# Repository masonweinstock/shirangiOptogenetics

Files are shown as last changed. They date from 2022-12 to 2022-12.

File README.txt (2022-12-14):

12/14/2022

Unless otherwise noted, all scripts, designs, and circuits were designed and created by Mason Weinstock.

Contained here are notes of the hardware and software used to execute optogenetic experiments in Dr. Shirangi's research at Villanova University from 2021 onward.

Questions should be directed to research@qyka.org.

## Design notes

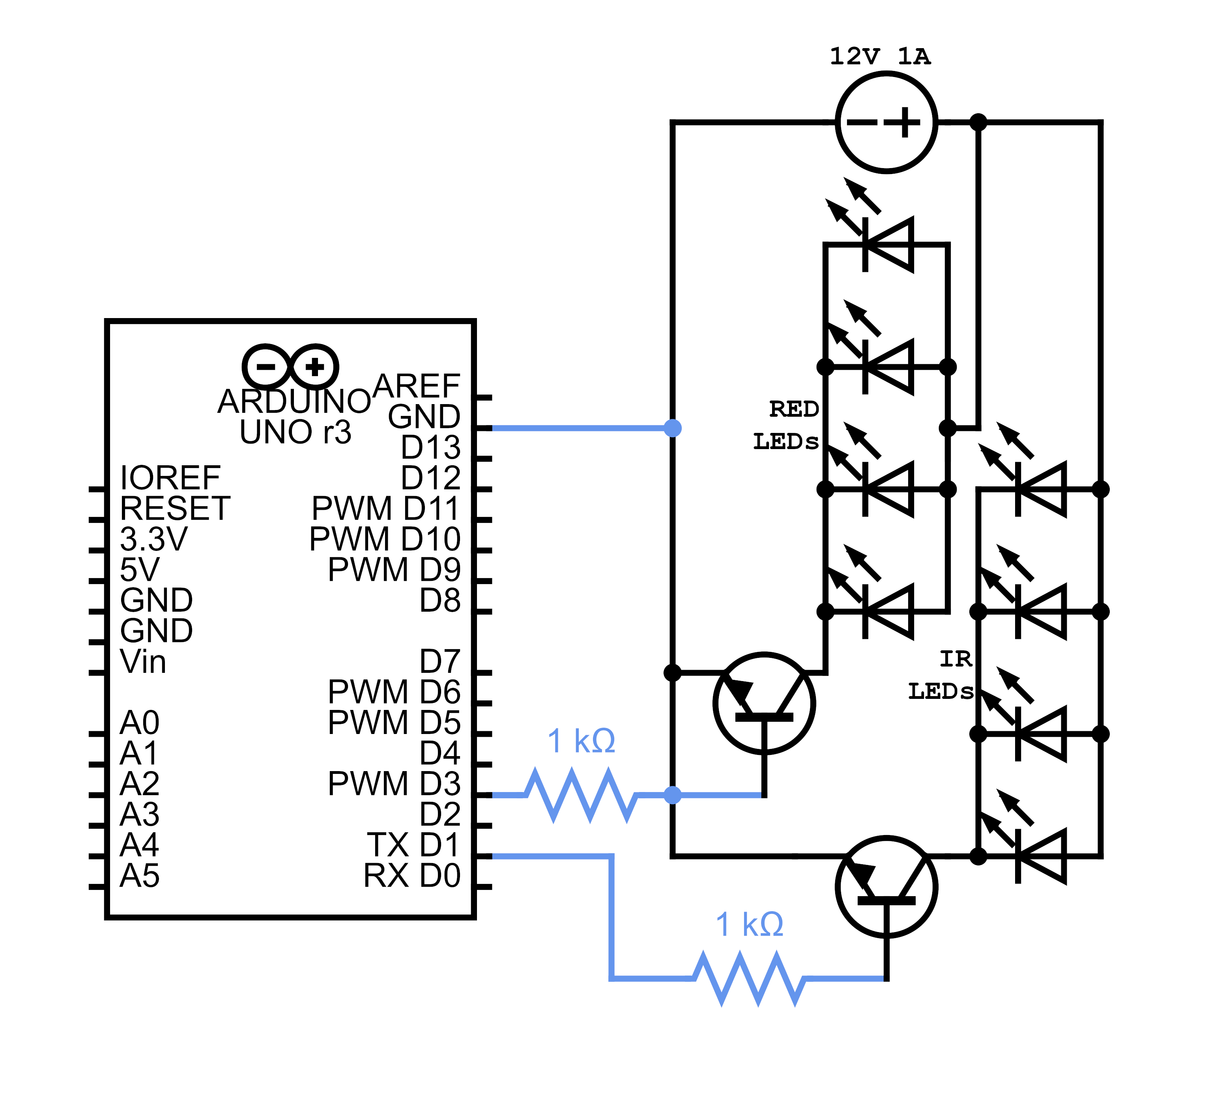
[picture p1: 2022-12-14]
circuit_diagram.png

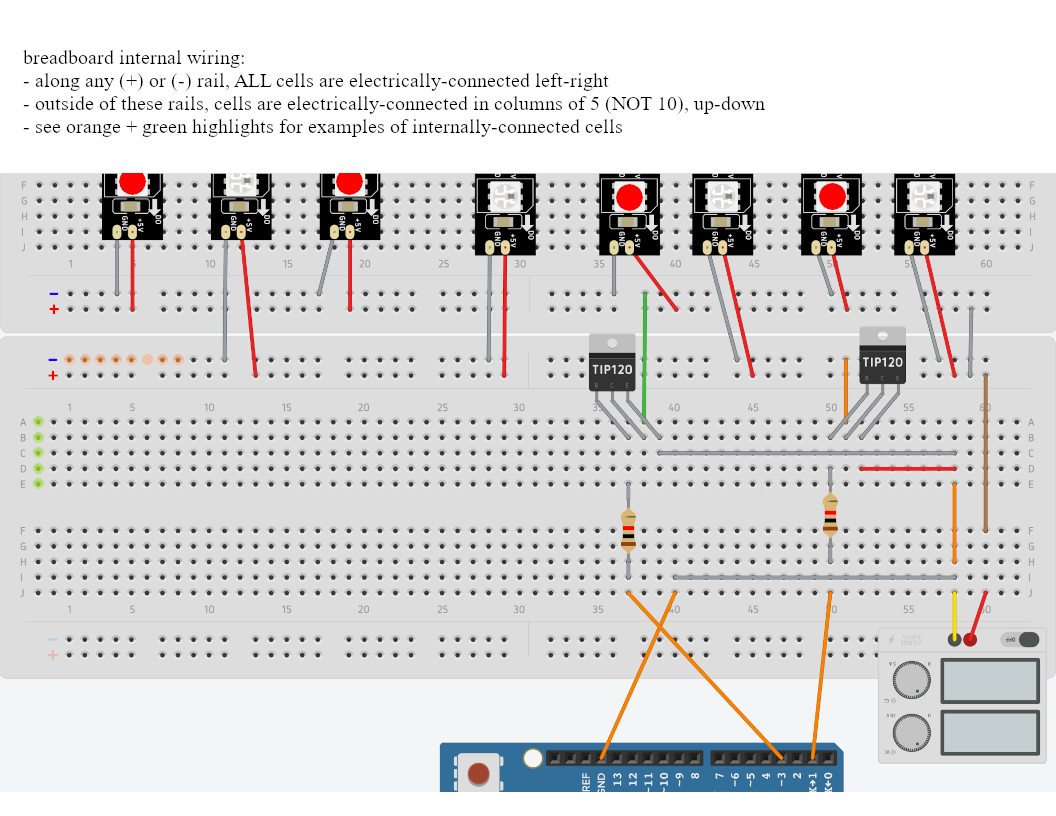
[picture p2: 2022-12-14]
breadboard_diagram.png

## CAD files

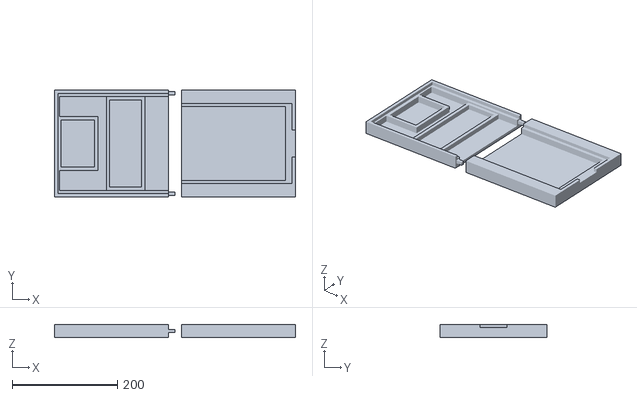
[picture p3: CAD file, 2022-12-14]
final v1 opto platform.stl
457.2 x 203.2 x 25.4

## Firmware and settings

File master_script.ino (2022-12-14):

/* 
 *  Written by Mason Weinstock for 2-transistor rig
 * Last updated: 12/12/22
 * 
 * To use script, change parameters below, plug in arduino and select 'Sketch->Upload.' This file is read-only such that
 * users don't overwrite default parameters. It is recommended users save parameters in an excperiment by selecting,
 * 'Save-As,' and creating a new file in the folder with the user's optogenetics videos.
 * 
 * See bottom of page for software AND hardware instructions 
 */

////////////////////////////////////////////////////////////////////////////////////////////////////////////////////////////////

// To change code/cycle parameters, edit the below values
        
        int numBouts;                 // users ignore
        #define ambient 1            // pin to IR backlights
        #define active 3             // [MUST BE ODD #] pin to red/green + indicator lights

        unsigned long lightOn = 15;   // time (sec) the active lights will be on each cycle
        unsigned long lightOff = 45;  // time (sec) the active lights will be off each cycle
        unsigned long prepTime = 60;  // time (sec) after boot-up before signal to record
        int numFlashes = 3;          // # of flashes indicating signal to begin recording
        int recordingWarning = 5;    // time (sec) after flashing signal for user to press record

// Operation mode: ramping or normal
        bool ramping = false;         // set to true if you want intensity to ramp
        int activeIntensity = 255;    // active light intensity for *NON-RAMPING* mode
        int activeIntensities[] = {    // active light intensities for *RAMPING* mode: default ramps +10%/cycle
            25, 50, 75, 100, 125, 150, 175, 200, 225, 255  
            };  
                                  
////////////////////////////////////////////////////////////////////////////////////////////////////////////////////////////////

void setup() {
    //convert human input -> arduino language //
    lightOn = lightOn * 1000;
    lightOff = lightOff * 1000;
    prepTime = prepTime * 1000;
    recordingWarning = recordingWarning * 1000;

    //deduce number of bouts desired by user
    numBouts = sizeof(activeIntensities)/sizeof(int);

    // setting  pins to output mode
    pinMode(ambient, OUTPUT);
    pinMode(active, OUTPUT);

   //turn on backlight, wait prepTime (sec)     
    digitalWrite(ambient, HIGH);
    delay(prepTime);

  // flash the backlights as
  // signal to press 'record'
    for(int i = 0; i < numFlashes; i++) {
        digitalWrite(ambient, LOW);              
        delay(500);                               
        digitalWrite(ambient, HIGH);               
        delay(500);            
    }
    // delay specified seconds, then begin main cycle
    delay(recordingWarning);
    loop();
}

void loop() {
  
      // ramping mode
      if(ramping==true) {

        // ramp intensity $numBouts times, with intensities of params
        for(int i = 0; i < numBouts; i++) {
          // turn active lights off for specified duration
          digitalWrite(active, LOW);
          delay(lightOff);
  
          // turn active lights on for specified duration
          analogWrite(active, activeIntensities[i]);
          delay(lightOn);
        }   
        
        // after ramping is done, turn lights off, end program
        digitalWrite(active, LOW);
        digitalWrite(ambient, LOW);
        exit(0);
      }

      // normal mode
      else {
        // turn active lights off for specified duration
        digitalWrite(active, LOW);
        delay(lightOff);

        // turn active lights on for specified duration
        analogWrite(active, activeIntensity);
        delay(lightOn);
      }
}

/* 
 *  Software
 *    Program flow
 *      After arduino is powered, IR backlights are powered for $prepTime seconds so the user can focus
 *      the camera, align chambers, attach indicator strip, etc. After this period, the backlights will
 *      flash $numFlashes times, signalling the user to press record on SpinView/DigitalViewer software.
 *      The user will then have $recordingWarning seconds to press record before the program's main loop
 *      will begin. The main loop begins with $lightOff seconds of only-IR exposure, before the first pulse
 *      of active lights for $lightOn seconds.
 *  
 *  Hardware
 *   Notes
 *     The power rails on this breadboard are not set up as usual. The (+) rails *will*
 *     act as a typical (+) rails (carrying current), but the (-) rails serves only to connect
 *     the various (-) ends of the lightstrips in parallel. They only connect to true ground (-)
 *     when the transistor is powered.
 * 
 *     The power rails on this breadboard are not set up as usual. The (+) rails *will*
 *     as a typical (+) rails (carrying current), but the (-) rails serves only to connect
 *     various (-) ends of the lightstrips in parallel. They only connect to true ground (-)
 *     the transistor is powered.
 *     
 *   Instructions:
 *     1. *Through a 1kOHM resistor*, connect pin 1 (base) of *each* transistor to its own arduino digi. pin, for switch control.
 *     2. Connect the power supply's (+) terminal to the closer of the two (+) rails. This rail is now powered.
 *     3. Connect the power supply's (-) terminal to an arbitrary row of 5 squares, which will be our grounding squares.
 *     4. Connect another square in this row to the arduino's digital GND pin, grounding it.
 *     5. Connect another square in this row to pin 3 (emitter) of transistor 1. Now these transistors are grounded... when the transistor is 'open.'
 *     6. Connect one of the transistor's middle pins (collector) its own (+) rail. E.g., connect transistor 1 (IR lights) to the closest (-) rail.
 *     7. Connect IR (+)-leads to this close (+) rail, and the (-) lead to the '(-) rail.' Remember that current only flows if transistor permits.
 *     8. Connect the two (+) rails with a wire, such that the power supply's (+) lead now powers both (+) rails.
 *     9. Repeat steps (5-7) for the other transistor, using the other (-) rail. Now the transistors and lightstrips will function independently of one another!
 *     9b. Step 8 must be repeated (wiring together the (+) rails), as must step 5 (middle pin to further (-) rail), whenever switching active light breadboard rails.
 */
